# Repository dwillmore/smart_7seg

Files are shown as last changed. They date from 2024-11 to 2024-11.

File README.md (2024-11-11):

# smart_7seg
Smart 7 segment display driver board

This board carries two 2 digit 7 segment displays and multiplexes them to display up to four characters.
Input is serial ASCII at 115200 baud.  The board will display the first four characters it sees after a newline or carrage return.  It will then pass through any remaining characters until the next carrage return or newline.  This allows boards to be cascaded from left to right to add more digits to the display in a manner that is invisible to the user.

The board is based off of the WCH CH32V003 chip in a TSSOP20 pin package.  It has an 0604 1uF capacitor as a decoupling cap and four AO3416 mosfets for the digit drivers.  It is designed to run at 3.3V and works with standard red and green displays.  It may also work with modern GaN displays, but that has not been tested.

The boards were fabricated by JLCPCB and designed with KiCAD 8.0.
Schematic:

Front Copper:

Back Copper:


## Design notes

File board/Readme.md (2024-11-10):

# KiCAD and fabrication files for JLCPCB

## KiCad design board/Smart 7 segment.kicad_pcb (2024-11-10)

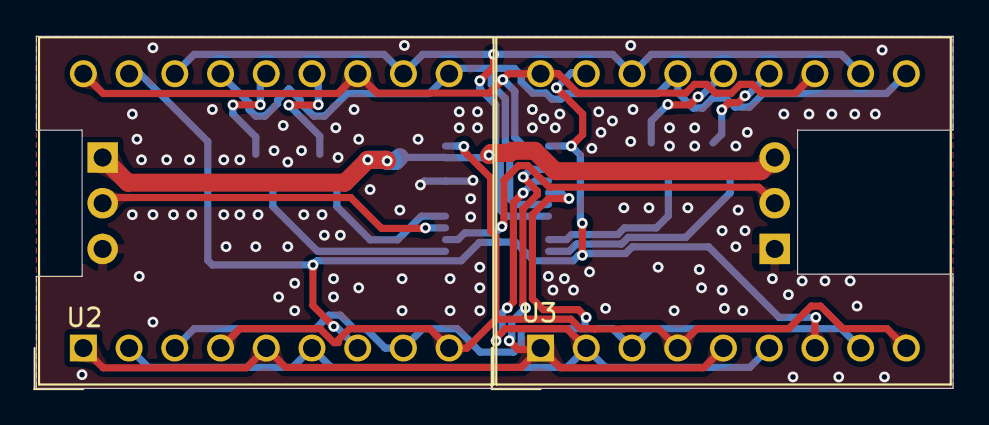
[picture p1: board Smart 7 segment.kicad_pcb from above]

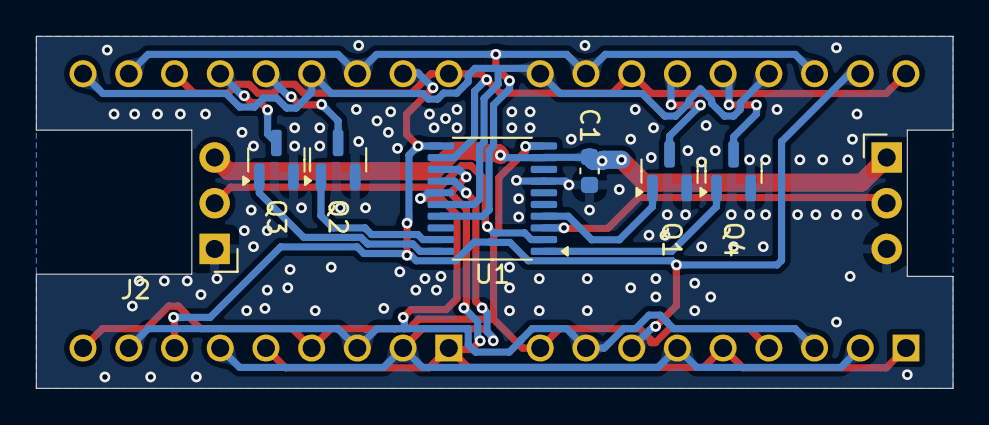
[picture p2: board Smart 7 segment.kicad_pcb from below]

Board: 2 copper layers, 50.9 x 19.6 mm, 10 parts (8 on the bottom side), 20 nets.

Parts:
C1: C; C_0603_1608Metric
J1, J2: Conn_01x03_Pin; PinHeader_1x03_P2.54mm_Horizontal
Q1, Q2, Q3, Q4: AO3400A; SOT-23
U1: CH32V003FxPx; TSSOP-20_4.4x6.5mm_P0.65mm
U2, U3: DC56-11CGKWA; DA56-11CGKWA

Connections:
GND: C1.2, J1.3, J2.1, Q1.2 (S), Q2.2 (S), Q3.2 (S), Q4.2 (S), U1.7 (VSS)
unnamed: J1.2, U1.3 (PD6)
unnamed: J2.2, U1.2 (PD5)
unnamed: Q1.3 (D), U2.13 (DIG2_CC)
unnamed: Q1.1 (G), U1.4 (PD7)
unnamed: Q2.3 (D), U3.14 (DIG1_CC)
unnamed: Q2.1 (G), U1.19 (PD2)
unnamed: Q3.3 (D), U3.13 (DIG2_CC)
unnamed: Q3.1 (G), U1.20 (PD3)
unnamed: Q4.3 (D), U2.14 (DIG1_CC)
unnamed: Q4.1 (G), U1.1 (PD4)
unnamed: U1.10 (PC0), U2.4 (DP1), U2.9 (DP2), U3.4 (DP1), U3.9 (DP2)
unnamed: U1.11 (PC1), U2.7 (DIG2_G), U2.17 (DIG1_G), U3.7 (DIG2_G), U3.17 (DIG1_G)
unnamed: U1.12 (PC2), U2.12 (DIG2_F), U2.18 (DIG1_F), U3.12 (DIG2_F), U3.18 (DIG1_F)
unnamed: U1.13 (PC3), U2.1 (DIG1_E), U2.5 (DIG2_E), U3.1 (DIG1_E), U3.5 (DIG2_E)
unnamed: U1.14 (PC4), U2.2 (DIG1_D), U2.6 (DIG2_D), U3.2 (DIG1_D), U3.6 (DIG2_D)
unnamed: U1.15 (PC5), U2.3 (DIG1_C), U2.8 (DIG2_C), U3.3 (DIG1_C), U3.8 (DIG2_C)
unnamed: U1.16 (PC6), U2.10 (DIG2_B), U2.15 (DIG1_B), U3.10 (DIG2_B), U3.15 (DIG1_B)
unnamed: U1.17 (PC7), U2.11 (DIG2_A), U2.16 (DIG1_A), U3.11 (DIG2_A), U3.16 (DIG1_A)
VCC: C1.1, J1.1, J2.3, U1.9 (VDD)

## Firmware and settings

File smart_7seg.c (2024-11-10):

#include "ch32v003fun.h"
#include <stdio.h>

#include "font.h"

#define digit0 PD4
#define digit1 PD7
#define digit2 PD2
#define digit3 PD3
#define num_digits 4

uint8_t digits[] = {	digit0,
											digit1,
											digit2,
											digit3 };

#define segmentA PC7
#define segmentB PC6
#define segmentC PC5
#define segmentD PC4
#define segmentE PC3
#define segmentF PC2
#define segmentG PC1
#define segmentDP PC0
#define num_segments 8

uint8_t segments[] = {  segmentA,
												segmentB,
												segmentC,
												segmentD,
												segmentE,
												segmentF,
												segmentG,
												segmentDP };

uint power[] = {1000, 100, 10, 1};
volatile uint current_digit = 0;
volatile uint8_t display_buf[num_digits];

#define SYSTICK_DELAY ((uint32_t)FUNCONF_SYSTEM_CORE_CLOCK / 1000)

void setDigit(uint8_t character){
	for(int i=0; i < num_segments; i++)
		if(font[character] & 1<<i)
			funDigitalWrite( segments[i], FUN_HIGH )
		else
			funDigitalWrite( segments[i], FUN_LOW );
}

void SysTick_Handler(void) __attribute__((interrupt));
void SysTick_Handler(void)
{
	SysTick->CMP += SYSTICK_DELAY;
	SysTick->SR = 0x00000000;
	for(int i = 0; i < num_digits; i++)
		funDigitalWrite( digits[i], FUN_LOW);
	setDigit(display_buf[current_digit]);
	funDigitalWrite( digits[current_digit], FUN_HIGH);
	if(current_digit++ == num_digits)
		current_digit = 0;
}

int main()
{
	uint count = 0;
	uint loops = 0;
	SystemInit();
	funGpioInitAll();
	enum State_t {  First_char,
									Second_char,
									Third_char,
									Fourth_char,
									Passthrough,
									EOL_ignore };
	enum State_t State = First_char;
	uint8_t in_char;
	
	// Setup digit select pins
	for(int i=0; i < num_digits; i++){
		funPinMode( digits[i], GPIO_Speed_2MHz | GPIO_CNF_OUT_PP );
		funDigitalWrite( digits[i], FUN_LOW );
	}

  // Setup segment pins
	for(int i=0; i < num_segments; i++){
		funPinMode( segments[i], GPIO_Speed_2MHz | GPIO_CNF_OUT_PP );
	  funDigitalWrite( segments[i], FUN_LOW );
	}

  // Setup serial pins and function
	SetupUART( UART_BRR );
	funPinMode( PD6, GPIO_CNF_IN_FLOATING );
	USART1->CTLR1 |= USART_CTLR1_RE;

  // Setup SysTicK based IRQ routine to run once a ms
	SysTick->CTLR = 0x0000;
	SysTick->CMP = SYSTICK_DELAY - 1;
	SysTick->CNT = 0x00000000;
	SysTick->CTLR |= SYSTICK_CTLR_STE | SYSTICK_CTLR_STIE | SYSTICK_CTLR_STCLK;
	NVIC_EnableIRQ(SysTicK_IRQn);

	for(int i = 0; i < num_digits; i++)
		display_buf[i] = 0;

	while(1)
	{
	  if(USART1->STATR & USART_STATR_RXNE){
			in_char = USART1->DATAR;
			switch(State){
				case First_char:
					display_buf[0] = in_char;
					State = Second_char;
					break;
				case Second_char:
					display_buf[1] = in_char;
					State = Third_char;
					break;
				case Third_char:
					display_buf[2] = in_char;
					State = Fourth_char;
					break;
				case Fourth_char:
					display_buf[3] = in_char;
					State = Passthrough;
					break;
				case Passthrough:
					if((in_char == 13) || (in_char == 10))
						State = EOL_ignore;
					printf("%c", in_char);
					break;
				case EOL_ignore:
					if((in_char == 13) || (in_char == 10)){
					  printf("%c", in_char);
					}else{
					  display_buf[0] = in_char;
						State = Second_char;
					}
					break;
			}
		}
	}
	while(1)
	{
		for(int dig=0; dig<num_digits; dig++){
			display_buf[dig] = ((count/power[dig])%10 + 48);
		}
		Delay_Ms(1);
		if(loops++ > 9){
			loops = 0;
			if(count++ > 9999) count = 0;
		}
	}
}

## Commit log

2024-11-10 Update README.md
    Add schematic image
2024-11-10 Update README.md
    Add board images
2024-11-10 Add files via upload
    KiCAD source and JLCPCB fab files
    [Smart 7 segment.kicad_pcb]
2024-11-11 Update README.md
    Replace PCB images.
